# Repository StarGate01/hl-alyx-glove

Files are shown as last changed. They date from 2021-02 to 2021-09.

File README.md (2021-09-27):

# Half-Life: Alyx Gravity Glove Replica
Firmware, Hardware and Models for a [Half-Life: Alyx](https://store.steampowered.com/app/546560/HalfLife_Alyx/) inspired glove cosplay prop. Based around an ATMega328p / Arduino Uno.

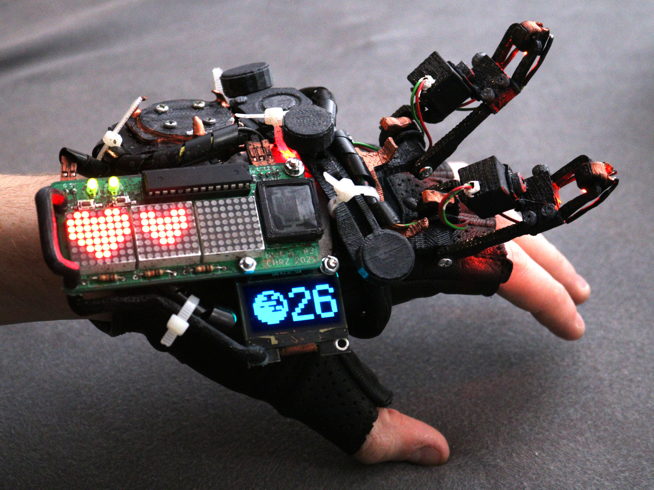
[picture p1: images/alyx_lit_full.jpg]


Also check out the [other images](https://github.com/StarGate01/hl-alyx-glove/tree/master/images)!

## Features

 - Detailed replica of the secondary-hand glove
   - Based on in-game 3D models
 - Custom printed circuit board
   - Small and compact due to SMD design
   - Three red LED matrices for hearts
   - Two individually controllable green status LEDs
   - Two orange finger attractor LEDs
   - Blue 128x64 pixel OLED screen for resin count
   - Red check engine LED light 
   - Moveable attractor fingers
 - Uses standard components for power source and control
 - Microcontroller can be easily reprogrammed
 - Cosmetic parts are printable on any standard 3D printer

## State of the Project

<details>
  <summary>PCB Revision 1: Proof of concept - Completed</summary>

  - [x] OLED rendering of resin count and sprite
  - [x] Display animations on 3 LED matrices
  - [x] Drive 2 green status LEDs
  - [x] Drive check engine LED
  - [x] Evaluate barebone IC
  - [x] Evaluate display drivers
  - [x] Manufacture board
  - [x] Validate board

</details>
 
<details>
  <summary>PCB Revision 2: Refinement - Completed</summary>

  - [x] Add buttons
  - [x] Add 0.1uF caps to driver ICs
  - [x] Larger power traces
  - [x] Re-think trace width in general
  - [x] Properly lay out mounting holes
  - [x] Optimize VCC trace
  - [x] Move OLED connector
  - [x] Optimize board size
  - [x] Think about inertial measurement unit
  - [x] Drive decorative yellow LEDs
  - [x] Improve ground plane stitching
  - [x] Add source info to silkscreen
  - [x] Add component orientation to  silkscreen
  - [x] Evaluate acceleration sensor
  - [x] Manufacture board
  - [x] Validate board

</details>

<details>
  <summary>Firmware Revision 1: Tests - Completed</summary>

  - [x] Test sensor
  - [x] Display resin count
  - [x] Display blinking hearts
  - [x] Flash LEDs
  - [x] Read buttons

</details>

<details>
  <summary>Firmware Revision 2: Demo mode - Completed</summary>

  - [x] State management w/ buttons
  - [x] LED control
  - [x] Adjustable amount of hearts and resin

</details>

<details>
  <summary>Firmware Revision 3: Proper functionality - In Progress</summary>

  - [ ] Wrist flick detection

</details>

<details>
  <summary>Power System - Completed</summary>

  - [x] Battery selection
  - [x] Charging management
  - [x] Verify power system

</details>

<details>
  <summary>CAD and 3D-Printing - Completed</summary>

  - [x] Acquire gloves
  - [x] Export models from game
  - [x] Design decorative parts
  - [x] Adapt decorative parts to 3D-Printing
  - [x] Think about paint and mounting
  - [x] Design battery holder
  - [x] Design PCB mount
  - [x] Mount to glove

</details>

<details>
  <summary>Final Assembly - Completed</summary>

  - [x] Proper paintjob
  - [x] Paint copper elements and add wires
  - [x] LED mounting

</details>

## Software

Clone this repository using `git clone` and open it up in the [PlatformIO IDE](https://platformio.org/).

Edit `include/hardware_config.h` if your pin layout differs.

Finally, use PlatformIO to compile and upload the program. A debug configuration for the Arduino Uno (`uno`) and a release configuration for the PCB (`barebone`) are available. To program the barebone chip, you need a ISP programmer such as a AVRISP, USBasp or Arduino as ISP.

### Compiling Modified Sprites

Use GIMP to export the `xcf` image files into `xdm` files. Make sure to declare the buffers as `PROGMEM`.

### Compiling Modified Fonts

Use a tool like `bdfedit` to view or edit the font.

Install `bdfresize` from your package manager.

Clone [olikraus/u8g2](https://github.com/olikraus/u8g2) and change into the `tools/font/bdfconv` directory. Run `make` and copy or link the `bdfconv` executable to somewhere you can run it.

Change into the `res` directory of this repository. Then run `./font.sh` to pre-compile the font.

## Software Components

 - Arduino
   - [Arduino Framework](https://www.arduino.cc/)
 - 8x8 mini 1.9mm LED matrix with MAX7219 IC using software SPI
   - [wayoda/LedControl](https://platformio.org/lib/show/914/LedControl)
 - 128x64 1.3 inch OLED using hardware I2C
   - [olikraus/U8g2](https://platformio.org/lib/show/942/U8g2)
 - GY-61 ADXL335 Breakout
   - Analog input

## Electronics

Most parts are pretty standard, eg. THT resistors, capacitors and LEDs. Pretty much any electronics store should carry them.

The main controller is a ATMega328p, the same as the Arduino Uno uses. These ICs are cheap for what they offer and also available pretty much everywhere.

The 1.9mm LED matrices are a special part, because they are the "mini" version of the much more widely used 3.0mm/3.75mm 8x8 LED matrices. I bought them from [AliExpress](https://de.aliexpress.com/item/4000931195417.html). The OLED is a fairly standard "Arduino-type" breakout board, and commonly available in blue, yellow and white. [Amazon](https://www.amazon.com/gp/product/B07D9G11DZ) carries them, and so does [AliExpress](https://de.aliexpress.com/item/1005001355009919.html). 

The surface mount LED is a 5050 SMT LED, which is also commonly used in LED strips and can be found at many stores, for example at [Ebay](https://www.ebay.com/itm/LED-Light-SMD-SMT-0603-0805-1206-7030-3020-5730-5050-3528-335-Super-bright/302940504403).

The display drivers are MAX7219CWG ICs, available at many stores, for example [Ebay](https://www.ebay.com/itm/10-St%C3%BCcke-Maxim-MAX7219CWG-SOP-24-Led-Display-Driver-New-Ic-ln/332191432560). However, prices differ a lot depending on the retailer.

The Acceleration sensor is an ADXL335 IC on the GY-61 "Arduino-type" breakout PCB. These modules are so cheap that it is not worth the trouble of including components that can't be hand-soldered. These modules are available at Amazon/Ebay and other retailers.

The power system consists of a 3.7V LiPo Battery commonly used for drones and RC toys (available from e.g. [Ebay](https://www.ebay.com/itm/151372678869)), and an integrated charger/converter board, which is for example available at [Amazon](https://www.amazon.de/gp/product/B07QHTK791). For interfacing, a micro USB socket is used.

### Fabricating the PCB

A [KiCad](https://kicad.org/) project is available in the `hardware` directory. It requires my [custom components](https://github.com/StarGate01/KiCadLibs).

Fabricate the PCB according to the Gerber files in `hardware/gerber` or send them to a factory. I had mine produced by [JLCPCB](https://jlcpcb.com/). All SMD components are hand-solderable using a fine tip and a steady hand.

Solder the components to the PCB according to the KiCAD schematics. Pay extra attention to the orientation of the LED displays and the display drivers ICs, check the little circle markers on the PCB. Sometimes the orientation of the LED matrices is not obvious, so just put them into the holes without soldering and tilt them to jam them, in order to make electrical contact. Then you can verify the orientation if they display correctly.

The mounting holes of the PCB and the OLED module should be on top of each other, such that the modules can be screwed together using an M3 bolt. The acceleration module can be soldered onto the PCB.

## Putting the Glove Together

The actual gloves are called "Half-Jab" by the company Highway 21. Available at motorcycle shops or Amazon/Ebay.

The directory `models` contains STL files for 3D printing. Please note that quite a lot of manual finishing is required depending on your printer. Print all the files in black plastic (I used PLA). The parts are not plug-and-play, you have to sand, cut and drill at various places. Use the parts as a starting point for your own creativity.

Refer to the photos to see how I assembled my version. I used silver metallic automotive sparypaint to color the base piece, and special copper colored paint to paint the copper elements. The rest was painted using acrylic colors.

The attractor LEDs are standard orange LEDs that were inserted into the tips of the finger pieces from above. Their power cables have been routed through a hole in the plastic and back to the PCB.

The "Check engine light" is a 3D printed frame with a piece of printed overhead foil. The frame then gets half-filled with semi-transparent hot glue to create a light diffusor. Print the document `models/check_engine.pdf` on overhead projection foil using a laser/toner printer and cut out one image to size. Insert the foil piece into the frame from the back, such that it rests on the small lip. Make sure the toner side faces inwards, such that it is not exposed to the outside. Then pour in some epoxy or hot glue, but make sure to not fill it up completely. Then position the lamp cover on the PCB where the frame is printed on. I attached it with some small drops of hot glue.

I used various M3 bolts and nuts, and some epoxy glue for the rest of the assembly. The whole assembly is attached to the glove without modifying the glove, instead relying on the two plastic hooks. Use some white zip-ties and some black spiral cable wrap to complete the look.

## Using the PCB

Press the button `SW1` to cycle through the effects, and `SW2` to change / cycle the selected effect. The selection order is: LED hearts amount (initial state) - Green status LED D1 - Green status LED D2 - Red "Check engine" LED D3 - Orange attractor LEDs L1 and L2 - LCD resin count.

## Licensing

All files in this repository are released under the terms of the MIT license. However the original idea and in-game design of the Half-Life: Alyx Glove was made by Valve Software. The copyright of the in-game design is of course held by Valve Software. The files in this repository however are a derivative / transformative work made by the author, and their copyright remains with the author.

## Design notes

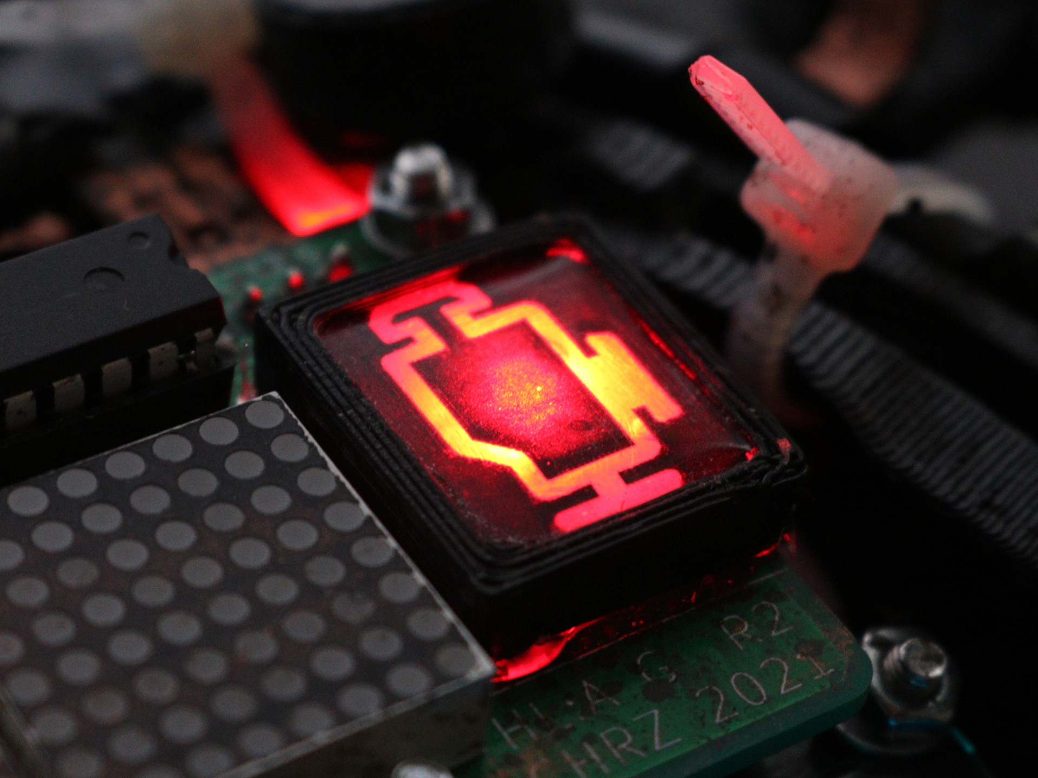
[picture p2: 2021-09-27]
images/alyx_engine.jpg

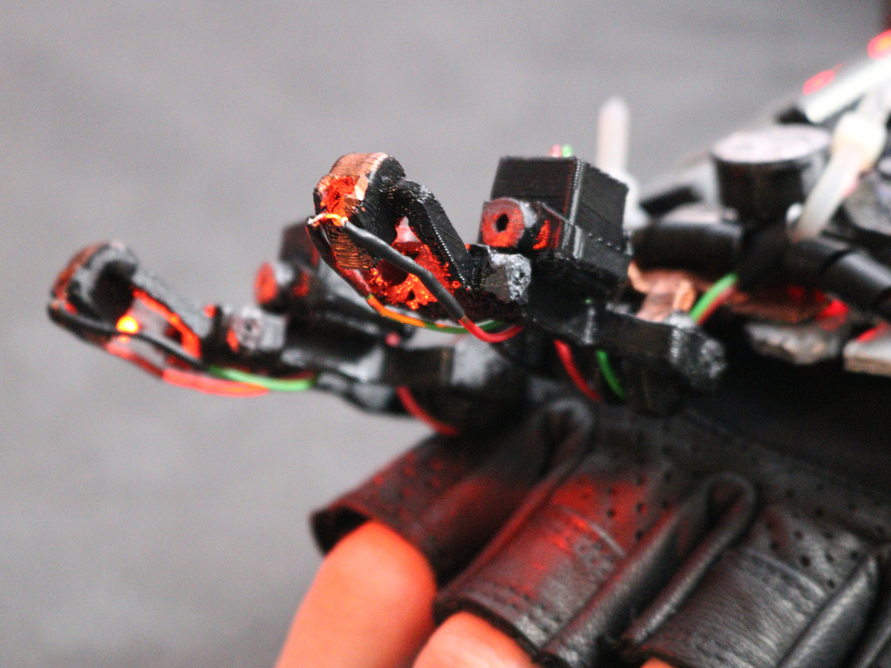
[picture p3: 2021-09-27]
images/alyx_finger.jpg

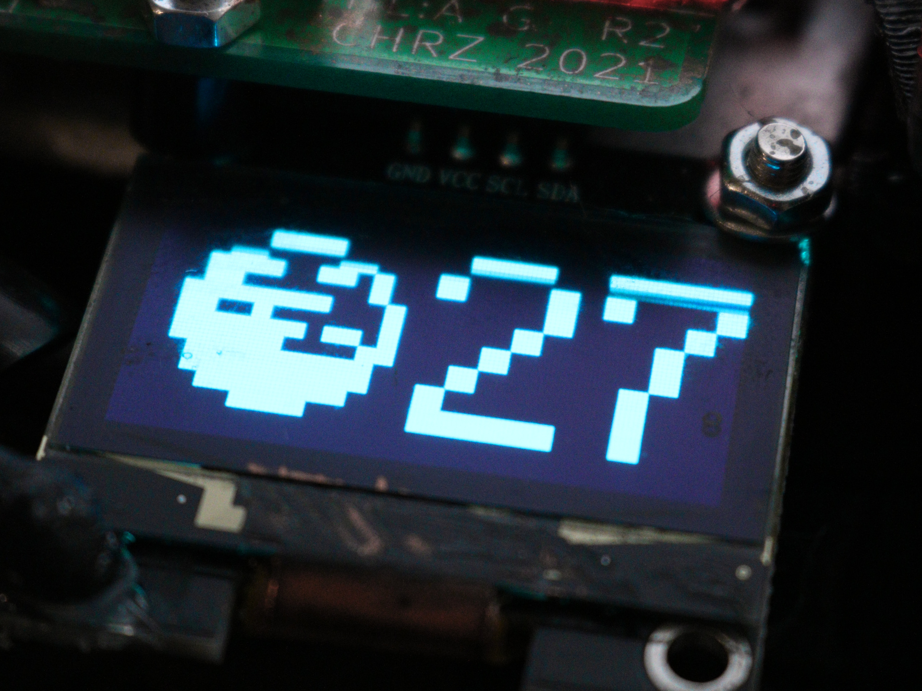
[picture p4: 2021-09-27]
images/alyx_oled.jpg

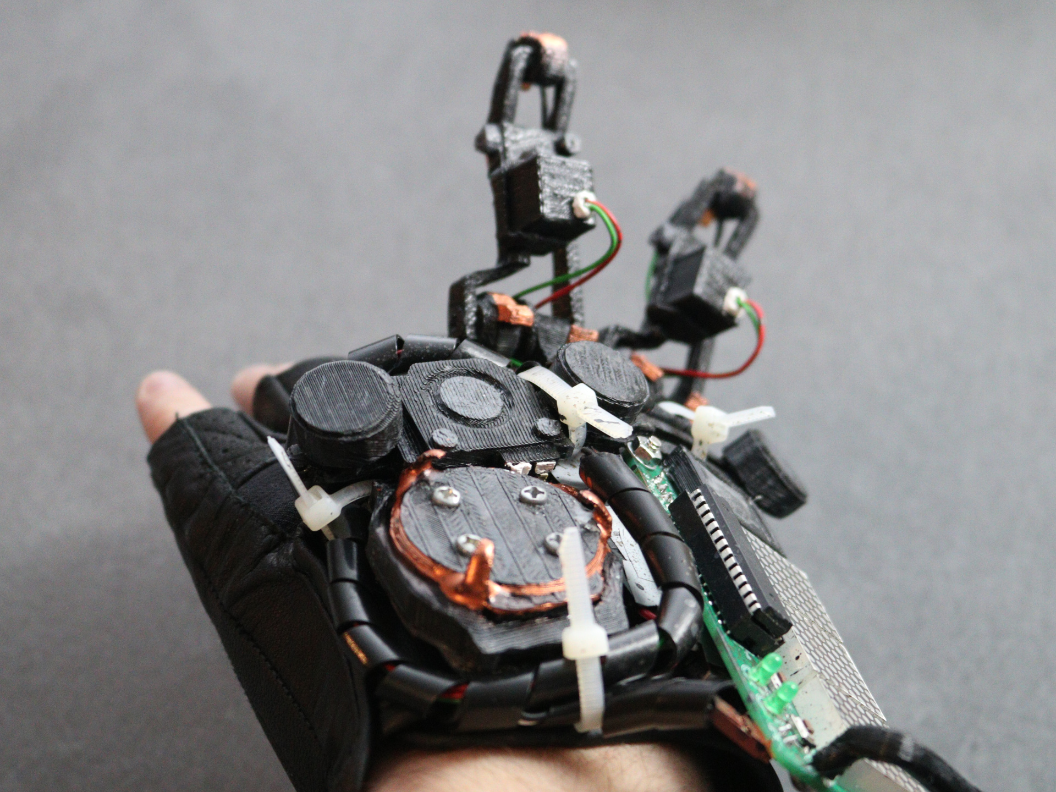
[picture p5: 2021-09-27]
images/alyx_unlit_back.jpg

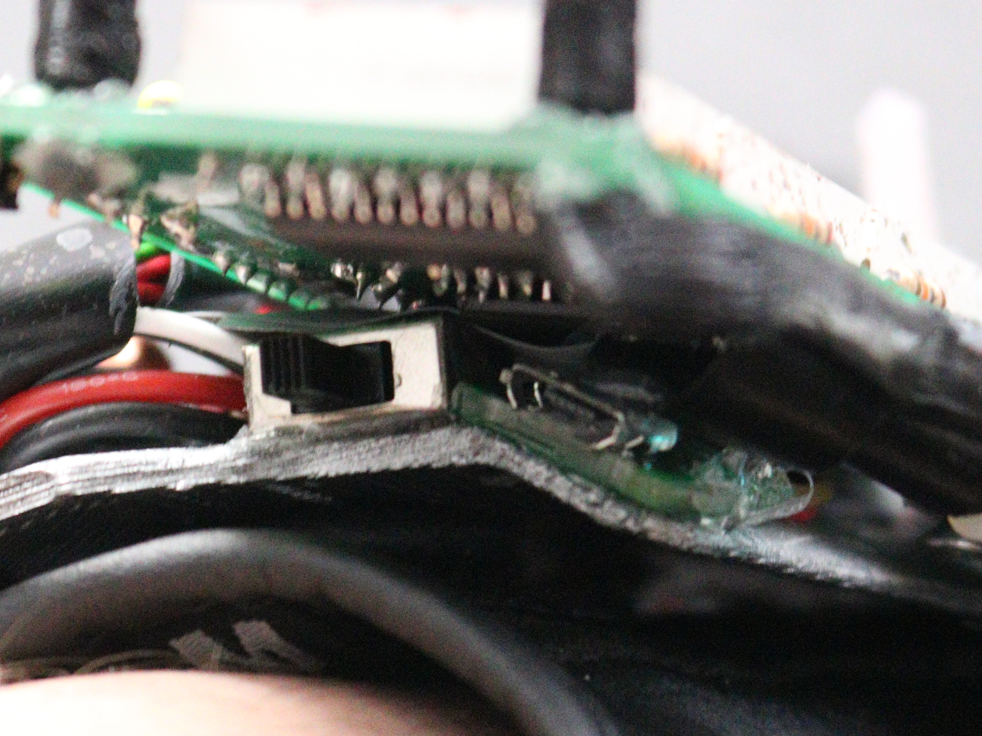
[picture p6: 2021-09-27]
images/alyx_switch.jpg

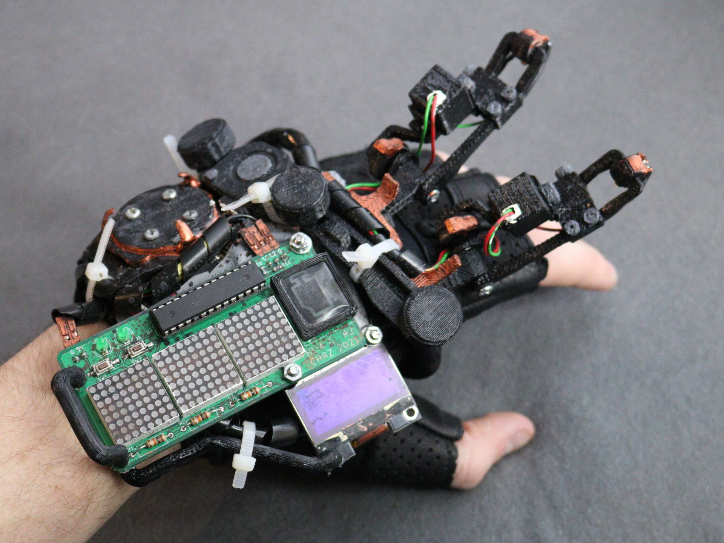
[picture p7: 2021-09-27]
images/alyx_unlit_front.jpg

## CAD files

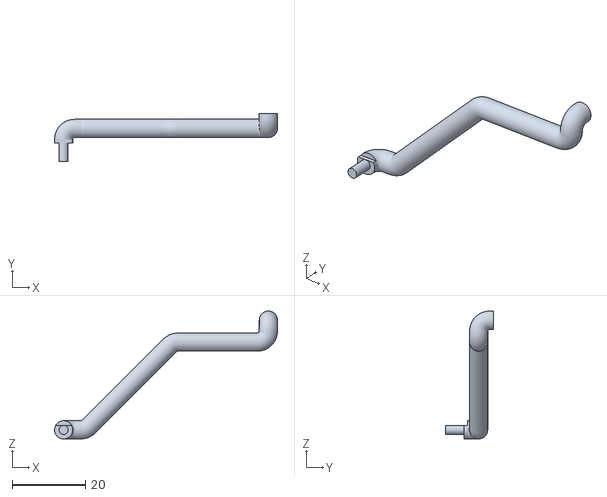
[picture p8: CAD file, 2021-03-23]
models/Bumper_Bottom.stl
61.0 x 13.0 x 35.0

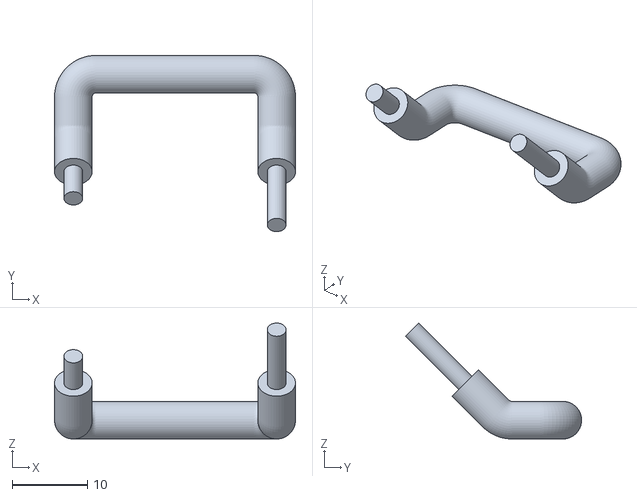
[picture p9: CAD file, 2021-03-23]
models/Bumper_Top.stl
32.0 x 23.4 x 15.4

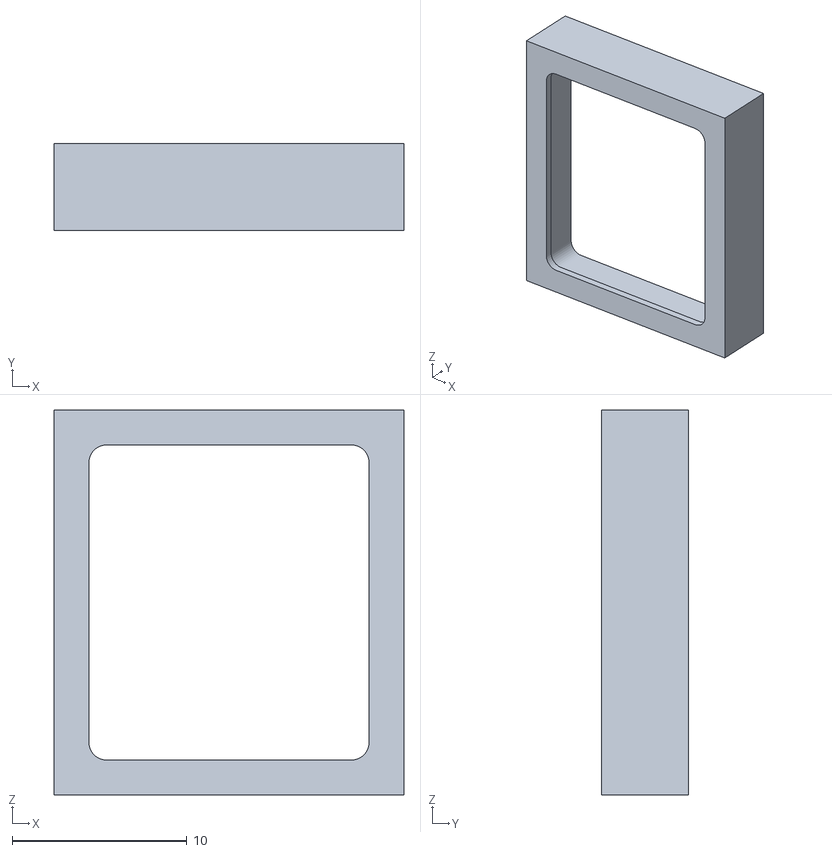
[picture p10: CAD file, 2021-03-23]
models/Lamp.stl
20.0 x 5.00 x 22.0

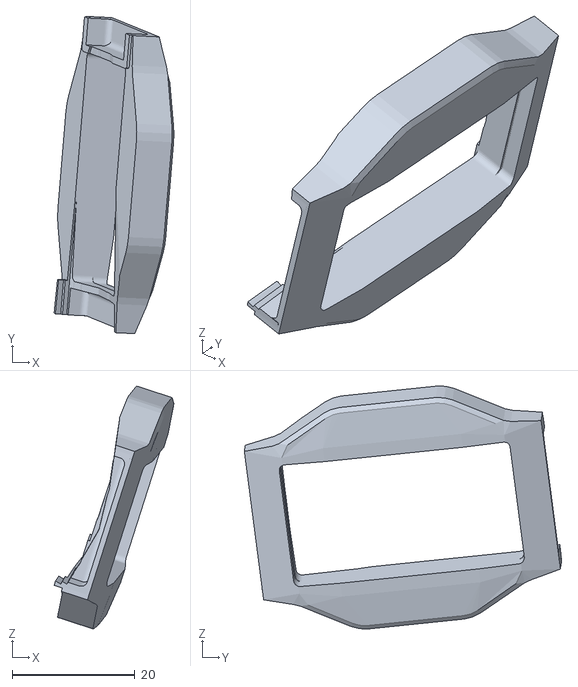
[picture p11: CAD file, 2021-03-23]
models/Battery_Case.stl
19.6 x 51.8 x 39.7

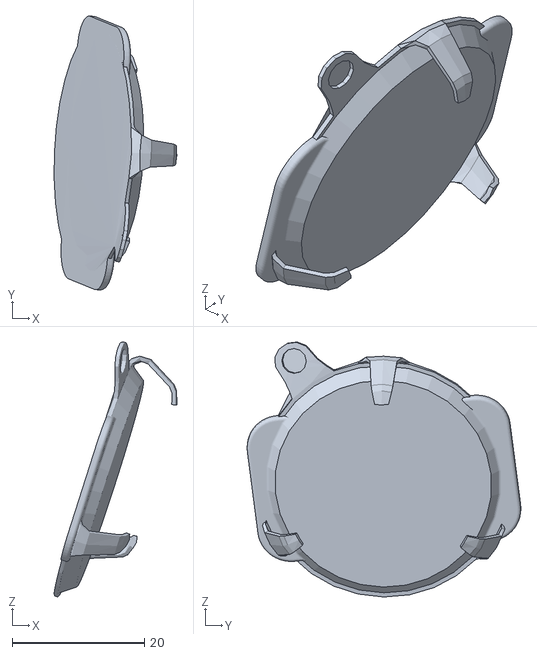
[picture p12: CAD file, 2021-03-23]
models/Battery_Cover.stl
18.5 x 41.4 x 38.5

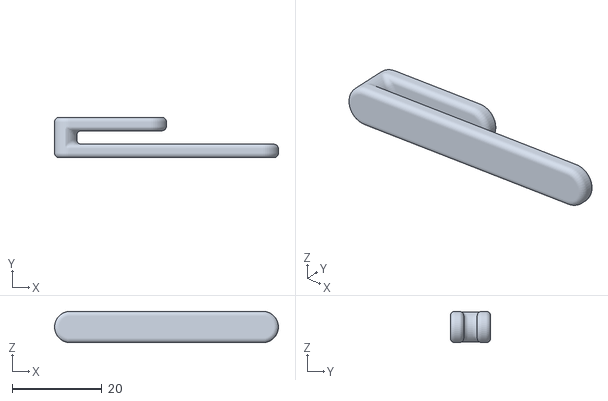
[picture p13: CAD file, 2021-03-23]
models/Clip.stl
50.0 x 9.00 x 7.00

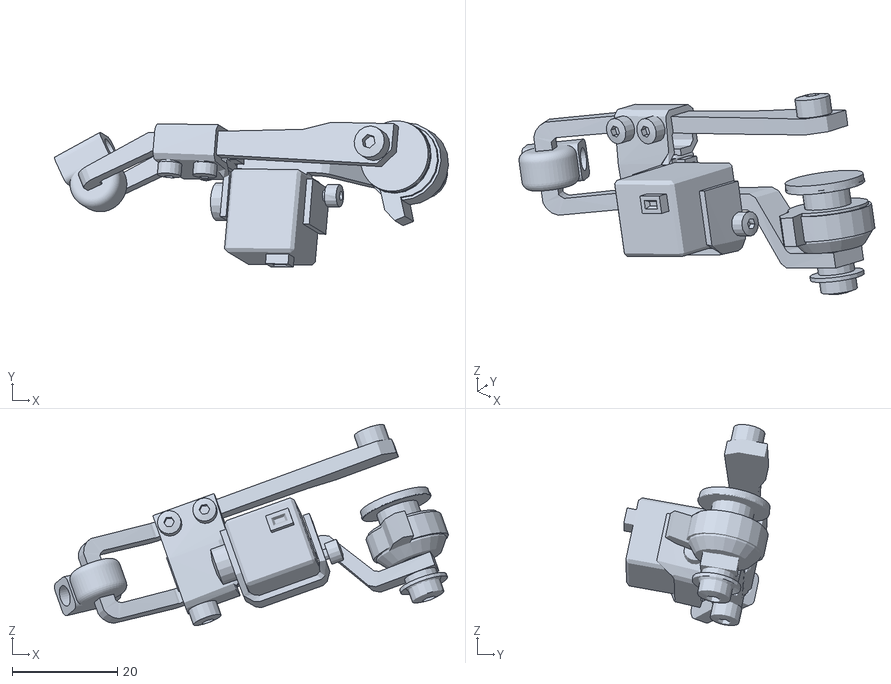
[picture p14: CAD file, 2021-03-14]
models/Finger.stl
74.7 x 27.7 x 38.1

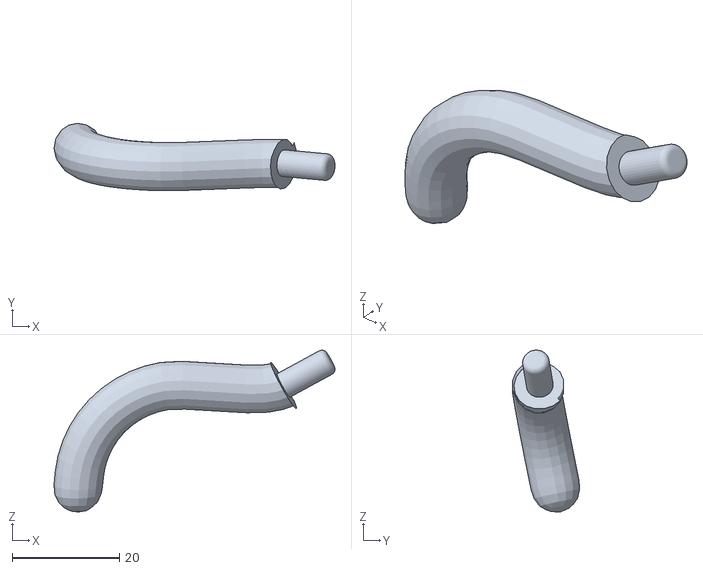
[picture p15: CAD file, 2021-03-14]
models/Hook.stl
52.5 x 12.6 x 30.2

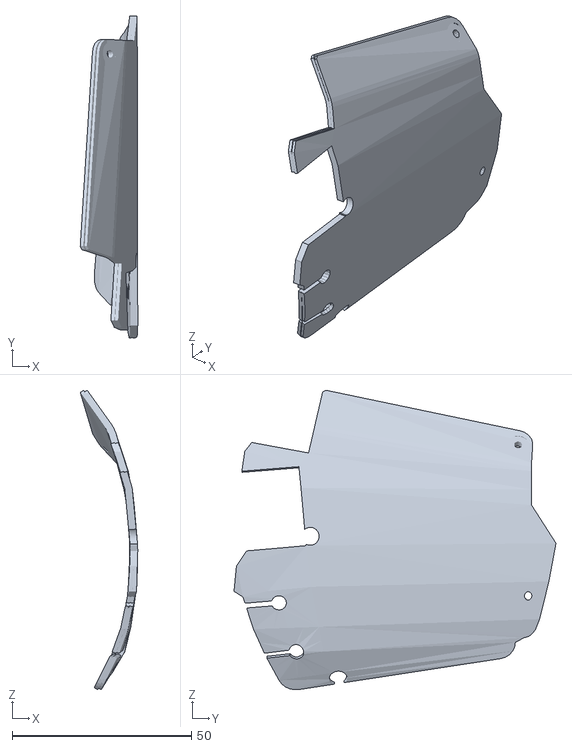
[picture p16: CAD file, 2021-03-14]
models/Base.stl
16.1 x 89.8 x 83.5

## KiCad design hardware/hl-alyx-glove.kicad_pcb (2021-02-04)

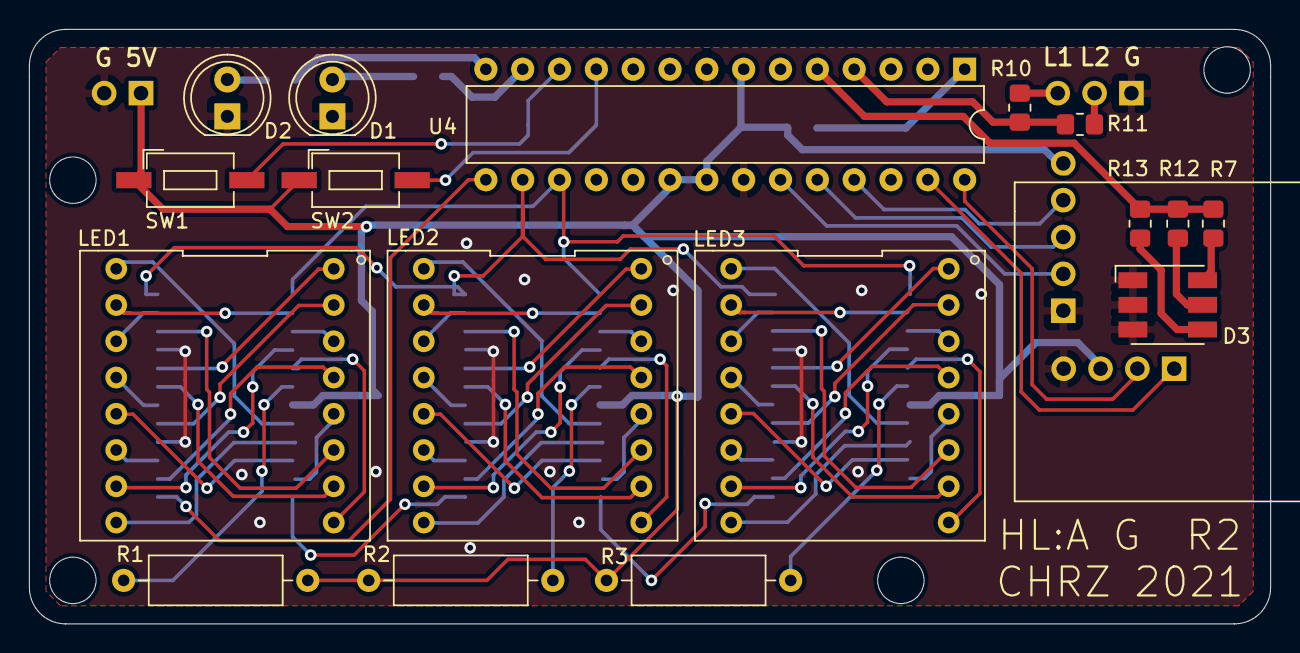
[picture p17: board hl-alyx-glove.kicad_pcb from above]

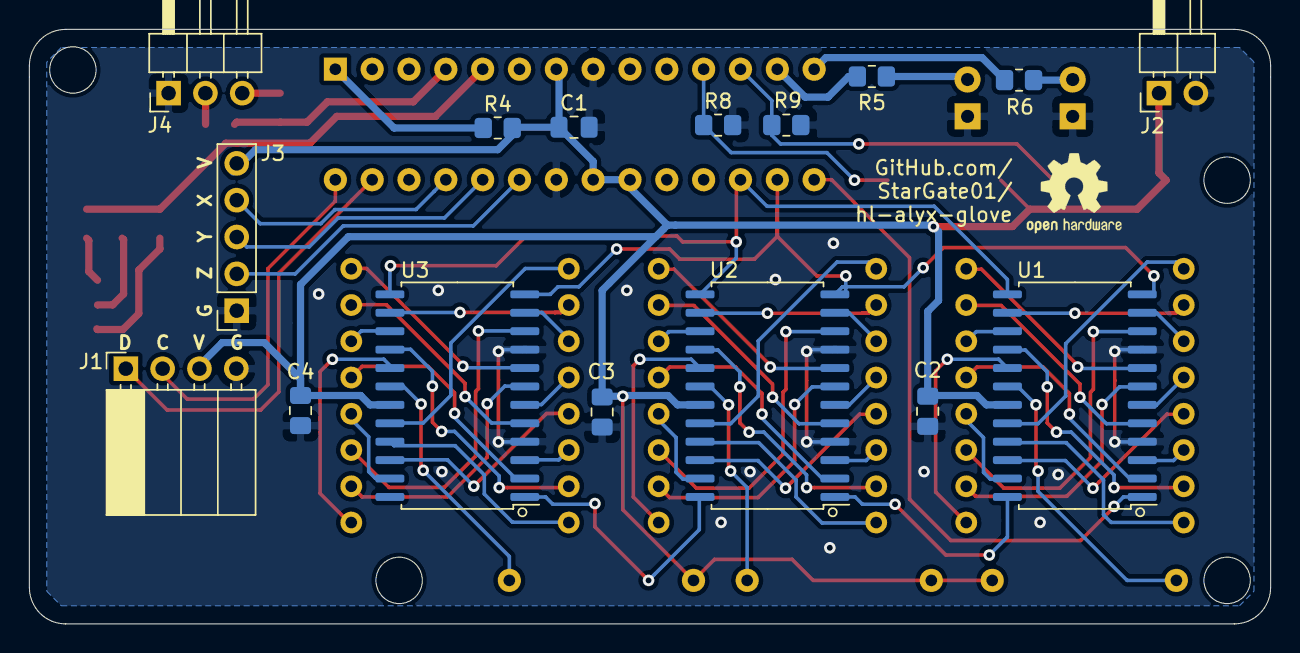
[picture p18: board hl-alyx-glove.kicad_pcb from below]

Board: 2 copper layers, 85.6 x 41.0 mm, 37 parts (16 on the bottom side), 77 nets.

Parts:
C1, C2, C3, C4: 100N; C_0805_2012Metric_Pad1.18x1.45mm_HandSolder
D1, D2: GREEN; LED_D5.0mm
D3: RED; LED_RGB_5050-6
H1, H2, H3, H4: MountingHole; MountingHole_3.2mm_M3_DIN965
J1: OLED; PinSocket_1x04_P2.54mm_Horizontal
J2: POWER; PinHeader_1x02_P2.54mm_Horizontal
J3: IMU; PinSocket_1x05_P2.54mm_Vertical
J4: EXT_LED; PinHeader_1x03_P2.54mm_Horizontal
LED1, LED2, LED3: 788BS
R1, R2, R3: 10K; R_Axial_DIN0309_L9.0mm_D3.2mm_P12.70mm_Horizontal
R4, R8, R9: 10K; R_0805_2012Metric_Pad1.20x1.40mm_HandSolder
R5, R6, R7, R10, R11, R12, R13: 180; R_0805_2012Metric_Pad1.20x1.40mm_HandSolder
SW1, SW2: SW_Push; smd_switch_sunrom4388
U1, U2, U3: MAX7219; SOP-24_7.5x15.4mm_P1.27mm
U4: ATmega328P-PU; DIP-28_W7.62mm

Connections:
/LED_Matrix_0/C1: LED1.5, U1.22
/LED_Matrix_0/C2: LED1.2, U1.14
/LED_Matrix_0/C3: LED1.7, U1.16
/LED_Matrix_0/C4: LED1.1, U1.20
/LED_Matrix_0/C5: LED1.12, U1.23
/LED_Matrix_0/C6: LED1.8, U1.21
/LED_Matrix_0/C7: LED1.14, U1.15
/LED_Matrix_0/C8: LED1.9, U1.17
/LED_Matrix_0/CLK: U1.13, U2.13, U3.13, U4.17
/LED_Matrix_0/DIN: U1.1, U4.15
/LED_Matrix_0/LOAD: U1.12, U2.12, U3.12, U4.16
/LED_Matrix_0/R1: LED1.13, U1.2
/LED_Matrix_0/R2: LED1.3, U1.11
/LED_Matrix_0/R3: LED1.4, U1.6
/LED_Matrix_0/R4: LED1.10, U1.7
/LED_Matrix_0/R5: LED1.6, U1.3
/LED_Matrix_0/R6: LED1.11, U1.10
/LED_Matrix_0/R7: LED1.15, U1.5
/LED_Matrix_0/R8: LED1.16, U1.8
/LED_Matrix_1/C1: LED2.5, U2.22
/LED_Matrix_1/C2: LED2.2, U2.14
/LED_Matrix_1/C3: LED2.7, U2.16
/LED_Matrix_1/C4: LED2.1, U2.20
/LED_Matrix_1/C5: LED2.12, U2.23
/LED_Matrix_1/C6: LED2.8, U2.21
/LED_Matrix_1/C7: LED2.14, U2.15
/LED_Matrix_1/C8: LED2.9, U2.17
/LED_Matrix_1/DIN: U1.24, U2.1
/LED_Matrix_1/R1: LED2.13, U2.2
/LED_Matrix_1/R2: LED2.3, U2.11
/LED_Matrix_1/R3: LED2.4, U2.6
/LED_Matrix_1/R4: LED2.10, U2.7
/LED_Matrix_1/R5: LED2.6, U2.3
/LED_Matrix_1/R6: LED2.11, U2.10
/LED_Matrix_1/R7: LED2.15, U2.5
/LED_Matrix_1/R8: LED2.16, U2.8
/LED_Matrix_2/C1: LED3.5, U3.22
/LED_Matrix_2/C2: LED3.2, U3.14
/LED_Matrix_2/C3: LED3.7, U3.16
/LED_Matrix_2/C4: LED3.1, U3.20
/LED_Matrix_2/C5: LED3.12, U3.23
/LED_Matrix_2/C6: LED3.8, U3.21
/LED_Matrix_2/C7: LED3.14, U3.15
/LED_Matrix_2/C8: LED3.9, U3.17
/LED_Matrix_2/DIN: U2.24, U3.1
/LED_Matrix_2/R1: LED3.13, U3.2
/LED_Matrix_2/R2: LED3.3, U3.11
/LED_Matrix_2/R3: LED3.4, U3.6
/LED_Matrix_2/R4: LED3.10, U3.7
/LED_Matrix_2/R5: LED3.6, U3.3
/LED_Matrix_2/R6: LED3.11, U3.10
/LED_Matrix_2/R7: LED3.15, U3.5
/LED_Matrix_2/R8: LED3.16, U3.8
GND: C1.2, C2.2, C3.2, C4.2, D1.1, D2.1, D3.1, D3.2, D3.3, J1.4, J2.2, J3.1, J4.1, R8.1, R9.1, U1.4, U1.9, U2.4, U2.9, U3.4, U3.9, U4.8, U4.22
unnamed: D1.2, R5.1
unnamed: D2.2, R6.1
unnamed: D3.4, R13.1
unnamed: D3.5, R12.1
unnamed: D3.6, R7.1
unnamed: J1.1, U4.27
unnamed: J1.2, U4.28
unnamed: J3.2, U4.23
unnamed: J3.3, U4.24
unnamed: J3.4, U4.25
unnamed: J4.2, R11.1
unnamed: J4.3, R10.1
unnamed: R1.1, U1.18
unnamed: R2.1, U2.18
unnamed: R3.1, U3.18
unnamed: R4.2, U4.1
unnamed: R5.2, U4.13
unnamed: R6.2, U4.14
unnamed: R8.2, SW2.2, U4.11
unnamed: R9.2, SW1.2, U4.12
unnamed: R10.2, R11.2, U4.4
unnamed: R7.2, R12.2, R13.2, U4.5
VCC: C1.1, C2.1, C3.1, C4.1, J1.3, J2.1, J3.5, R1.2, R2.2, R3.2, R4.1, SW1.1, SW2.1, U1.19, U2.19, U3.19, U4.7, U4.20, U4.21

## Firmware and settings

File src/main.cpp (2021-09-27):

// Setup and resources
#include "hardware_config.h"
#include "res.h"

// Libraries
#include <Arduino.h>
#include "LedControl.h"
#include "U8g2lib.h"


// Various parameters
#define FRAME_TIME 100
#define LEDMAT_NUM 3
#define LEDMAT_BRIGHTNESS 3
#define HEARTS_FRAMES 4

// Display drivers
LedControl lc(LED_DIN, LED_CLK, LED_CS, LEDMAT_NUM);
U8G2_SH1106_128X64_NONAME_F_HW_I2C u8g2(U8G2_R0);

// Core logic
unsigned int mode = 0, resin = 0;
unsigned int hearts_idx[3] = { 0, 0, 0 };
bool last_b1 = false, last_b2 = false;
bool l1 = false, l2 = false, lstat = false, lext = false;


void setup() 
{
    // LEDs
    pinMode(LED_CE, OUTPUT);
    pinMode(LED_EX, OUTPUT);
    pinMode(LED_S1, OUTPUT);
    pinMode(LED_S2, OUTPUT);

    // Sensor
    pinMode(ACC_X, INPUT);
    pinMode(ACC_Y, INPUT);
    pinMode(ACC_Z, INPUT);
    pinMode(BTN_1, INPUT);
    pinMode(BTN_2, INPUT);

    // LCD
    u8g2.begin();
    u8g2.setFont(hl_alyx);

    // Matrices
    delay(500);
    for(int i=0; i<LEDMAT_NUM; i++)
    {
        lc.shutdown(i, false);
        lc.setIntensity(i, LEDMAT_BRIGHTNESS);
        lc.clearDisplay(i);
    }
}

void loop() 
{
    // Read buttons
    bool b1 = digitalRead(BTN_1) == LOW;
    bool b2 = digitalRead(BTN_2) == LOW;

    // Mode button
    if(b1 && !last_b1)
    {
        mode++;
        mode = mode % 6;
    }
    last_b1 = b1;

    // Change button
    if(b2 && !last_b2)
    {
        if(mode == 0)
        {
            resin++;
            resin = resin % 100;
        }
        else if(mode == 1)
        {
            hearts_idx[0]++;
            if(hearts_idx[0] > HEARTS_FRAMES - 1)
            {
                hearts_idx[0]--;
                hearts_idx[1]++;
                if(hearts_idx[1] > HEARTS_FRAMES - 1)
                {
                    hearts_idx[1]--;
                    hearts_idx[2]++;
                    if(hearts_idx[2] > HEARTS_FRAMES - 1)
                    {
                        hearts_idx[0] = 0;
                        hearts_idx[1] = 0;
                        hearts_idx[2] = 0;
                    }
                }
            }
        }
        else if(mode == 2)
        {
            l1 = !l1;
            digitalWrite(LED_S1, l1);
        }
        else if(mode == 3)
        {
            l2 = !l2;
            digitalWrite(LED_S2, l2);
        }
        else if(mode == 4)
        {
            lstat = !lstat;
            digitalWrite(LED_CE, lstat);
        }
        else if(mode == 5)
        {
            lext = !lext;
            digitalWrite(LED_EX, lext);
        }
    }
    last_b2 = b2;

    // Draw LCD image
    u8g2.clearBuffer();
    u8g2.drawXBMP(ball_left, ball_top, ball_width, ball_height, ball_bits);
    if(resin > 9) u8g2.drawGlyph((LCD_WIDTH / 2) - 2, LCD_HEIGHT - FONT_OFFSET_Y, (resin / 10) + '0');
    else u8g2.drawGlyph((LCD_WIDTH / 2) - 2, LCD_HEIGHT - FONT_OFFSET_Y, ':');
    u8g2.drawGlyph(LCD_WIDTH - FONT_WIDTH, LCD_HEIGHT - FONT_OFFSET_Y, (resin % 10) + '0');
    u8g2.sendBuffer();

    // Draw hearts
    for(int k=0; k<8; k++) 
    {
        for(int i=0; i<3; i++)
        {
            lc.setRow(i, k, heart[hearts_idx[i]][k]);
        }
    }

    // Test the accelerometer
    // int x = max(0, min(255, (analogRead(ACC_X) * 3) / 128));
    // int y = max(0, min(255, (analogRead(ACC_Y) * 3) / 128));
    // int z = max(0, min(255, (analogRead(ACC_Z) * 3) / 128));
    // lc.setRow(0, 0, x);
    // lc.setRow(0, 1, y);
    // lc.setRow(0, 2, z);

    // Debounce
    delay(20);
}

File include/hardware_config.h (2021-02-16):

#ifndef CONFIG_H
#define CONFIG_H

// LED matrices
#define LED_DIN 9
#define LED_CLK 11
#define LED_CS  10

// LEDs
#define LED_CE 3
#define LED_EX 2
#define LED_S1 7
#define LED_S2 8

// Sensor
#define ACC_X A2
#define ACC_Y A1
#define ACC_Z A0
#define BTN_1 6
#define BTN_2 5

// LCD display
#define LCD_WIDTH  128
#define LCD_HEIGHT 64

#endif

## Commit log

2021-01-17 Add hardware
    [hl-alyx-glove.kicad_pcb, hl-alyx-glove.sch]
2021-01-17 schematic first version
    [LED0.sch, LED1.sch, LED2.sch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]
2021-01-17 add some missing components
    [LED_Matrix.sch, hl-alyx-glove.kicad_pcb, hl-alyx-glove.sch]
2021-01-19 pcb first version
    [LED_Matrix.sch, hl-alyx-glove.kicad_pcb, hl-alyx-glove.sch]
2021-01-19 Add rev 1 gerber files
    [hl-alyx-glove-B_Cu.gbr, hl-alyx-glove-B_Mask.gbr, hl-alyx-glove-B_SilkS.gbr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]
2021-01-27 Add barebone config, leds & resistor values
    [hl-alyx-glove.sch]
2021-02-01 small fix for barebone
    [hardware_config.h, main.cpp]
2021-02-04 PCB rev 2 first changes
    [LED_Matrix.sch, hl-alyx-glove.kicad_pcb, hl-alyx-glove.sch]
2021-02-04 add second led
    [LED_Matrix.sch, hl-alyx-glove.kicad_pcb, hl-alyx-glove.sch]
2021-02-04 add missing resistors to big led
    [LED_Matrix.sch, hl-alyx-glove.kicad_pcb, hl-alyx-glove.sch]
2021-02-04 small fixes
    [hl-alyx-glove.kicad_pcb]
2021-02-04 kicad save
    [LED_Matrix.sch]
2021-02-04 fix button footprints
    [LED_Matrix.sch, hl-alyx-glove.kicad_pcb, hl-alyx-glove.sch]
2021-02-04 small fix
    [hl-alyx-glove.kicad_pcb]
2021-02-04 Implement sensors
2021-02-04 Add rev 2 gerber files
    [hl-alyx-glove-B_Cu.gbr, hl-alyx-glove-B_Mask.gbr, hl-alyx-glove-B_SilkS.gbr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]
2021-03-14 Add models
    [Base.stl, Finger.stl, Hook.stl]
2021-03-23 Add rest of models
    [Battery_Case.stl, Battery_Cover.stl, Clip.stl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]
2021-03-23 add bumper models
    [Bumper_Bottom.stl, Bumper_Top.stl]
